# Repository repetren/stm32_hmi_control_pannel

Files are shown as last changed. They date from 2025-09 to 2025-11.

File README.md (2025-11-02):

# STM32 CAN Dashboard Panel

Control unit for generating CAN signals based on an STM32. Inputs from magnetic encoders, buttons, and a potentiometer.

My personal project with goal to expand my knowledge about industry standards communication protocols.

Created to provide interactive demo CAN inputs for my [Motorcycle Instrument Cluster project](https://github.com/repetren/moto_instrument_cluster).



Watch the video (https://youtu.be/6McVTvd34ow)

### [Watch demo and work in progress video on YouTube](https://youtu.be/6McVTvd34ow)



### Features:
- Timers for CAN frame transmission schedule  
- Buttons via EXTI
- Software button debounce
- LED indicators for power and mode indicators
- Two potentiometer modes for two CAN frames
- ADC with DMA for potentiometer sampling

### Power and ESD
- 5 V input, 3.3 V logic. Conversion through LD1117A regulator
- TVS diode for CAN bus and power input protection

## Project Structure

I'm using **[app.c](App/Src/app.c)** to avoid deal with USER CODE BLOCKs inside STM32 generated code.

**CAN_Control_Panel**

App:
- Inc - Header
- Src - Source - **main [app.c](App/Src/app.c)**

Core: Startup + HAL init (generated)
- Inc
- Src - **main.c** contains **app.c**

Docs:
- CAN message map

Hardware:
- PCB - Gerbers, BOM, circuit diagram
- 3DPrints - Knobs, buttons, frame .stl files

## Hardware
- STM32F446RET6 as main MCU
- 6 push buttons via EXTI interrupts
- 2 rotary encoders (AS5048B) over I2C
- 1 potentiometer with analog input
- CAN transceiver: SN65HVD230DR
- UART for debugging and serial output
- SWD interface for firmware flashing and debugging

## Software Architecture



The panel collects input data from physical controls and sensors, processes them periodically in the main loop, and sends formatted messages over CAN and UART.

| Input | Interface | Processed in | Purpose |
| :---: | --- | --- | --- |
| Buttons (6 pcs) | EXTI interrupts | EXTI + Debounce. | Gear, turn signals, potentiometer modes |
| Magnetic encoders (2 pcs) | I2C | `[encoder_remap](App/Src/encoder_utils.c)` | Angle to telemetry parameter |
| Potentiometer | ADC + DMA | `[fuel_and_temp_utils.c](App/Src/fuel_and_temp_utils.c)` | Fuel/temperature input (depending on mode) |

#### Periodic task handling ([app.c](App/Src/app.c))
Tasks are executed based on timing from the TIM14 timer.

|  Frequency | Task responsibilities |
| :---: | --- |
| **100 Hz** | Update telemetry, monitor temperature, send telemetry |
|  **50 Hz** | Update lights and send over CAN light frame |
|  **25 Hz** | Fuel conversion, range estimation, vehicle info broadcast, low fuel notification, CAN fuel frame send |

#### Output communication

| Output  | Used for |
| --- | --- |
| UART | Debug messages |
| CAN bus | Telemetry, light control, fuel, and notification frames sent to Raspberry Pi with CAN HAT |

## CAN Frame Map


## Build and run

### Requirements
 - VS Code
 - Installed [STM32CubeIDE for Visual Studio Code](https://marketplace.visualstudio.com/items?itemName=stmicroelectronics.stm32-vscode-extension)
 - [STLINK-V3MINIE](https://www.digikey.de/de/products/detail/stmicroelectronics/STLINK-V3MINIE/16284301)

### VS Code
1. Open repository folder
2. Configure project. CMD (CTRL) + Shift + P
```
Setup STM32Cube project(s)
```


3. Select device



4. Click "Save and close"

5. Run and debug



6. Select ST-LINK server

7. Select project .elf



8. Click "Continue" (F5)



## Future improvements
- Replacing big SWD 14-pin connector to 6-pin version

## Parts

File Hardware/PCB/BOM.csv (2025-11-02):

Reference | Qty | Value | DNP | Exclude from BOM | Exclude from Board | Footprint | Datasheet
C1,C2,C3,C4,C13 | 5 | 100nF |  |  |  | CL05B104KP5NNNC:CAPC1005X55N | ~
C5 | 1 | 2.2 µF |  |  |  | Capacitor_SMD:C_0402_1005Metric | ~
C6,C10 | 2 | 100 nF |  |  |  | CL05B104KP5NNNC:CAPC1005X55N | ~
C7,C15 | 2 | 4.7 µF |  |  |  | CL10A475KP8NNNC:CAPC1608X90N | ~
C8,C9 | 2 | 10μF |  |  |  | CL10A106KQ8NNNC:CAPC1608X90N | ~
C11,C12 | 2 | 20pF |  |  |  | C0603C200G8HACTU:CAPC17595_87N_KEM | ~
C14 | 1 | 10 uF |  |  |  | CL10A106KQ8NNNC:CAPC1608X90N | ~
CR1 | 1 | LD1117AS33TR |  |  |  | LD1117AS33TR:SOT-223_STM | https://www.st.com/resource/en/datasheet/ld1117a.pdf
D1,D2,D3,D4,D5,D9 | 6 | LED |  |  |  | LED_SMD:LED_1206_3216Metric | ~
D6 | 1 | SM712_SOT23 |  |  |  | Package_TO_SOT_SMD:SOT-23 | https://www.littelfuse.com/~/media/electronics/datasheets/tvs_diode_arrays/littelfuse_tvs_diode_array_sm712_datasheet.pdf.pdf
D7,D8 | 2 | SMF5V0A |  |  |  | Diode_SMD:D_SMF | https://www.vishay.com/doc?85881
DOWN_1,DOWN_2,LEFT_2,POT_MODE_1,RESET_1,RIGHT_2,UP_2 | 7 | B3FS-1012P |  |  |  | B3FS_1012P:B3FS-101_OMR | B3FS-1012P
J1,J2 | 2 | KF301-2P |  |  |  | KF301-2P:HANDSON_KF301-2P
J3 | 1 | FTSH-107-01-L-DV-K |  |  |  | FTSH_107_01_L_DV_K:SAMTEC_FTSH-107-01-L-DV-K
L1 | 1 | WE-CBF_0402 |  |  |  | 74279271:WE-CBF_0402_W1.5
Q1,Q2 | 2 | AS5048B-HTSP-500 |  |  |  | AS5048B-HTSP-500:TRANS_HTSP-500_AMS-M | AS5048B-HTSP-500
R1,R5,R7,R8,R9,R10,R11 | 7 | 120 Ohm |  |  |  | Resistor_SMD:R_0603_1608Metric | ~
R2,R3 | 2 | 4.7 kOhm |  |  |  | Resistor_SMD:R_0603_1608Metric | ~
R4 | 1 | 1 kOhm |  |  |  | Resistor_SMD:R_0603_1608Metric | ~
R6 | 1 | 10 kOhn |  |  |  | Resistor_SMD:R_0603_1608Metric | ~
R12 | 1 | 10 kOhm |  |  |  | Resistor_SMD:R_0603_1608Metric | ~
U1 | 1 | STM32F446RET6 |  |  |  | STM32F446RET6:QFP50P1200X1200X160-64N
U2 | 1 | P0915N-FC15BR10K |  |  |  | P0915N_FC15BR10K:SWITCH_C15BR10K_BIT | P0915N-FC15BR10K
U3 | 1 | SN65HVD230DR |  |  |  | SN65HVD230DR:SOIC127P599X175-8N
USART2 | 1 | ~ |  |  |  | Connector_PinHeader_2.54mm:PinHeader_1x04_P2.54mm_Vertical
Y1 | 1 | ECS-80-18-5PX-TR |  |  |  | ECS_80_18_5PX_TR:XTAL_ECS-80-18-5PX-TR

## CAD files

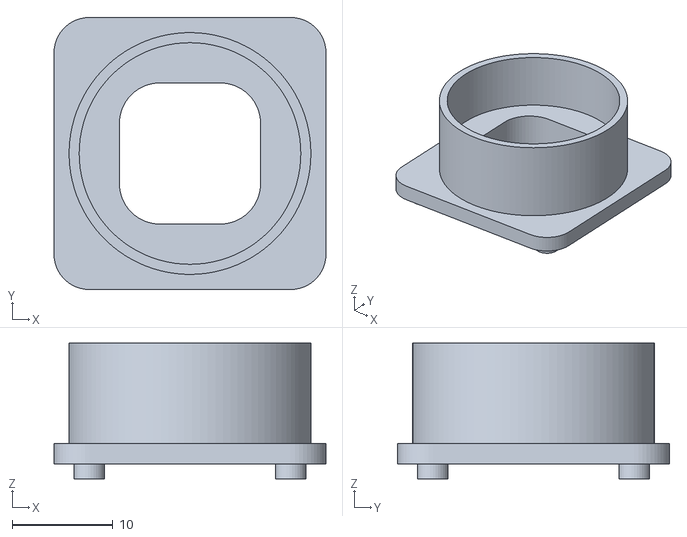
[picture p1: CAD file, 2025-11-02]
Hardware/3Dprints/Moto_HMI_ballbearing_holder_v002.stl
27.0 x 27.0 x 13.5

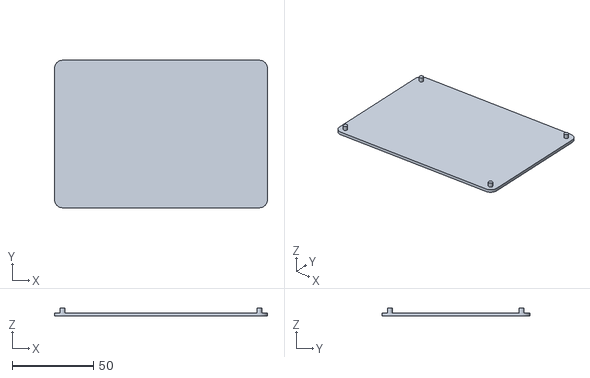
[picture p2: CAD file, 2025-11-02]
Hardware/3Dprints/Moto_HMI_bottom_blate_v002.stl
131.0 x 90.8 x 5.00

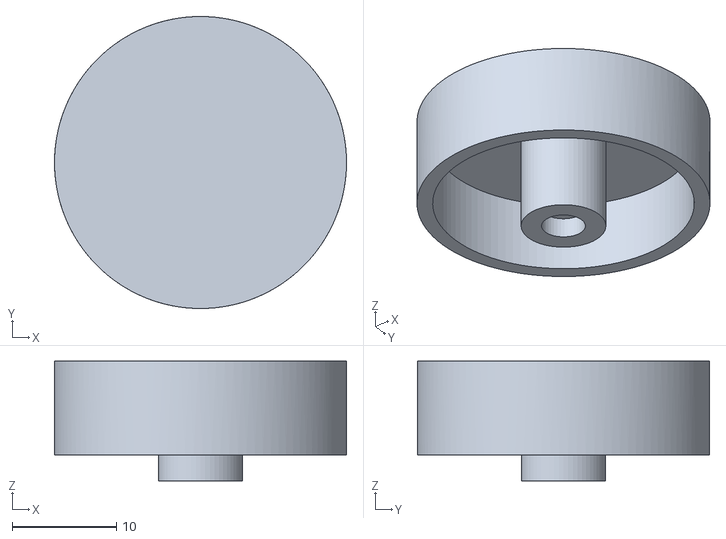
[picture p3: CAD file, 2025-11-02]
Hardware/3Dprints/Moto_HMI_Knob_v004.stl
28.0 x 28.0 x 11.5

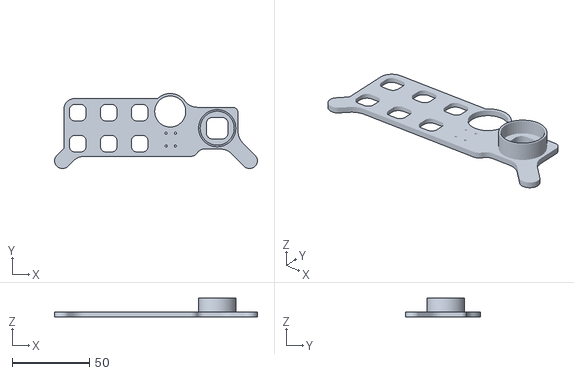
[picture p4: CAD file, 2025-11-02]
Hardware/3Dprints/Control_pannel_frame_v003.stl
131.0 x 48.4 x 12.0

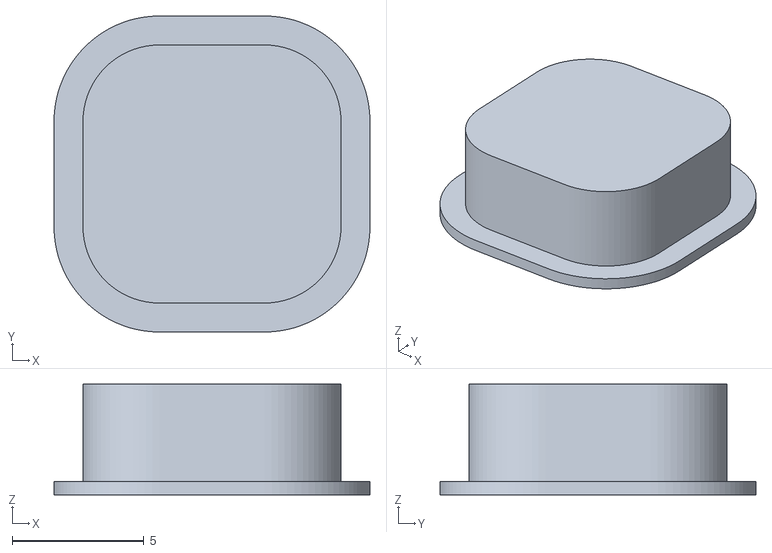
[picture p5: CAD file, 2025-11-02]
Hardware/3Dprints/control_pannel_button_v005.stl
12.0 x 12.0 x 4.20

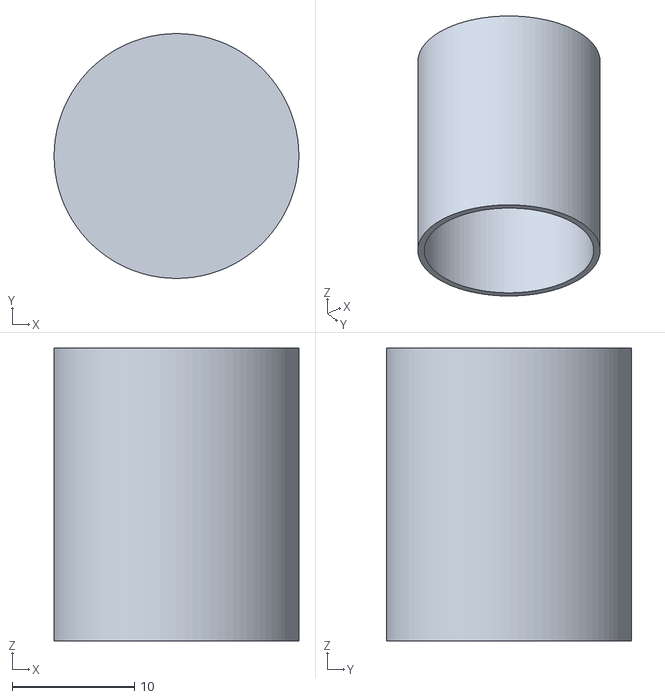
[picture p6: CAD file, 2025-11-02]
Hardware/3Dprints/Control_Pannel_knob_v001.stl
20.1 x 20.1 x 24.0

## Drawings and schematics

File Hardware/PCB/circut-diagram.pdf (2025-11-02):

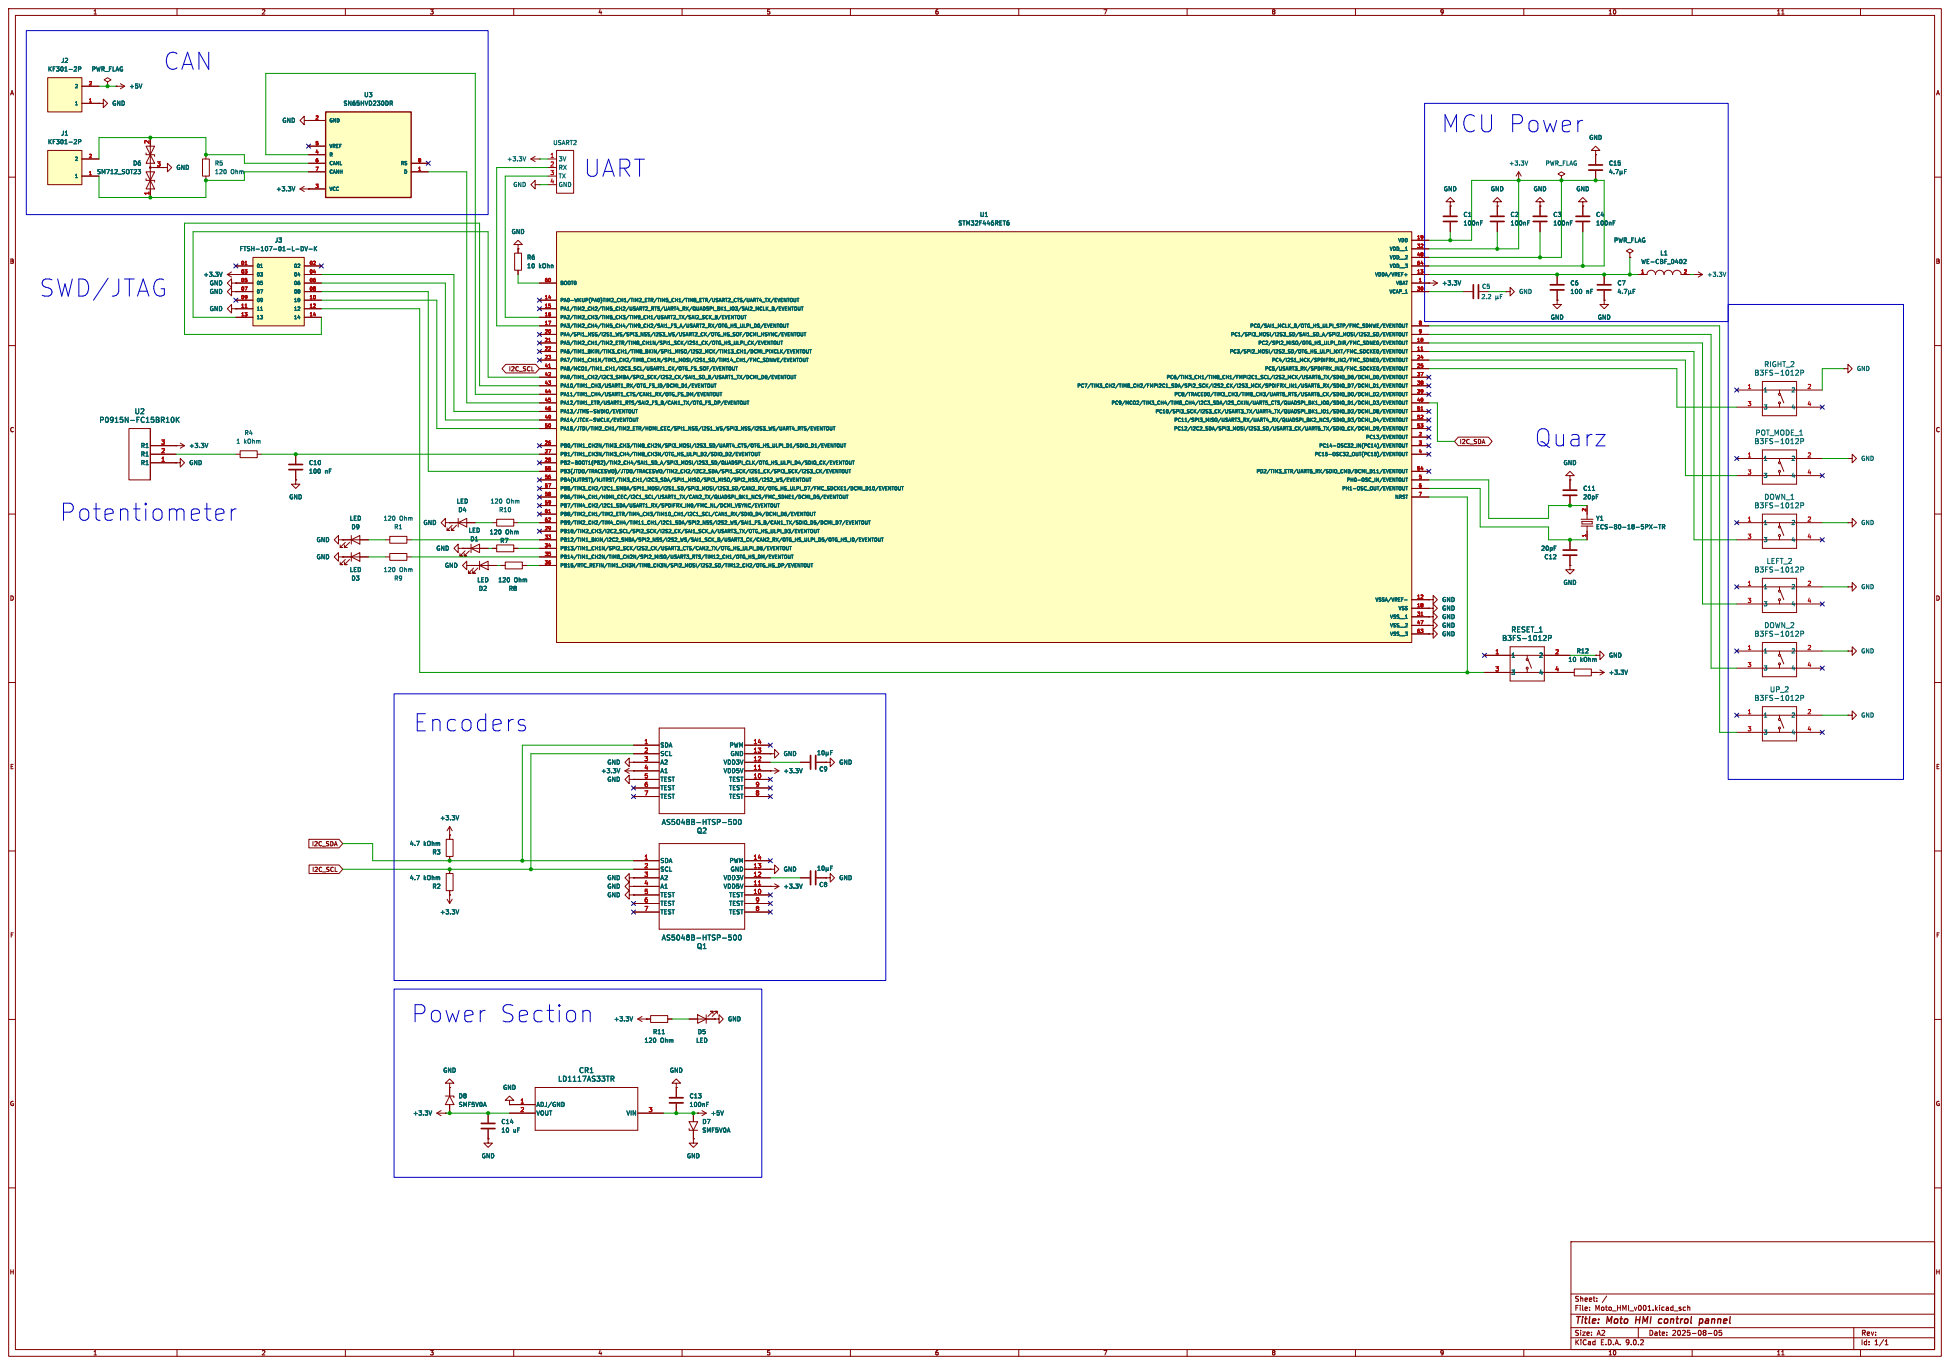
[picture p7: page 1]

GNDGND GND GND GND GND GND

GND GND GND GND GND

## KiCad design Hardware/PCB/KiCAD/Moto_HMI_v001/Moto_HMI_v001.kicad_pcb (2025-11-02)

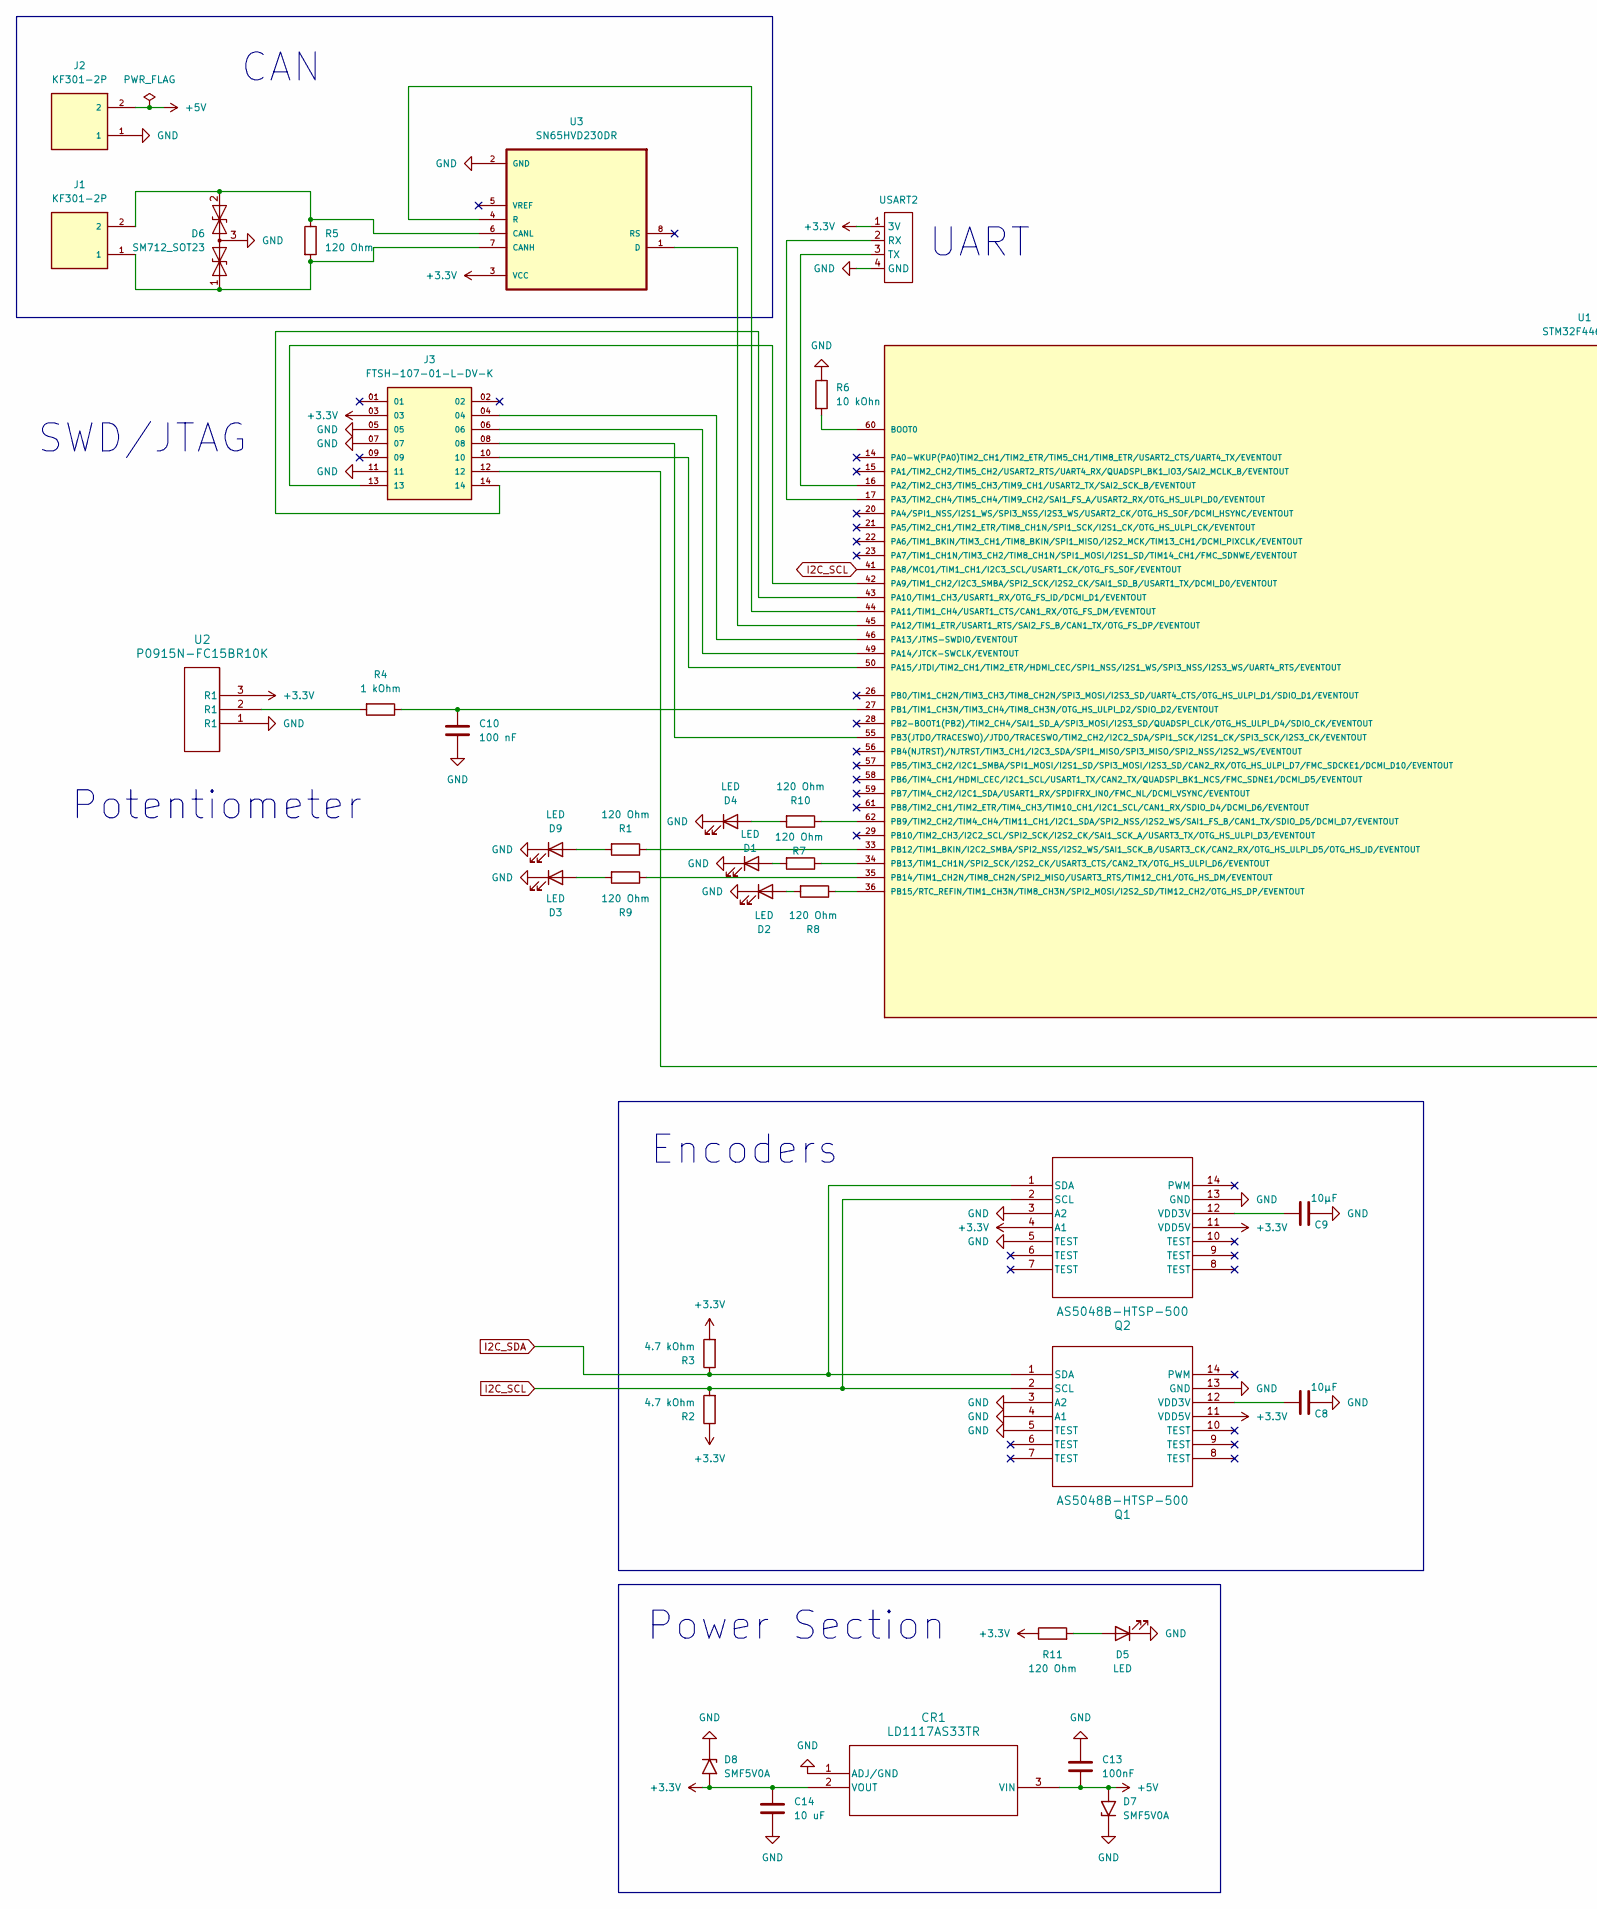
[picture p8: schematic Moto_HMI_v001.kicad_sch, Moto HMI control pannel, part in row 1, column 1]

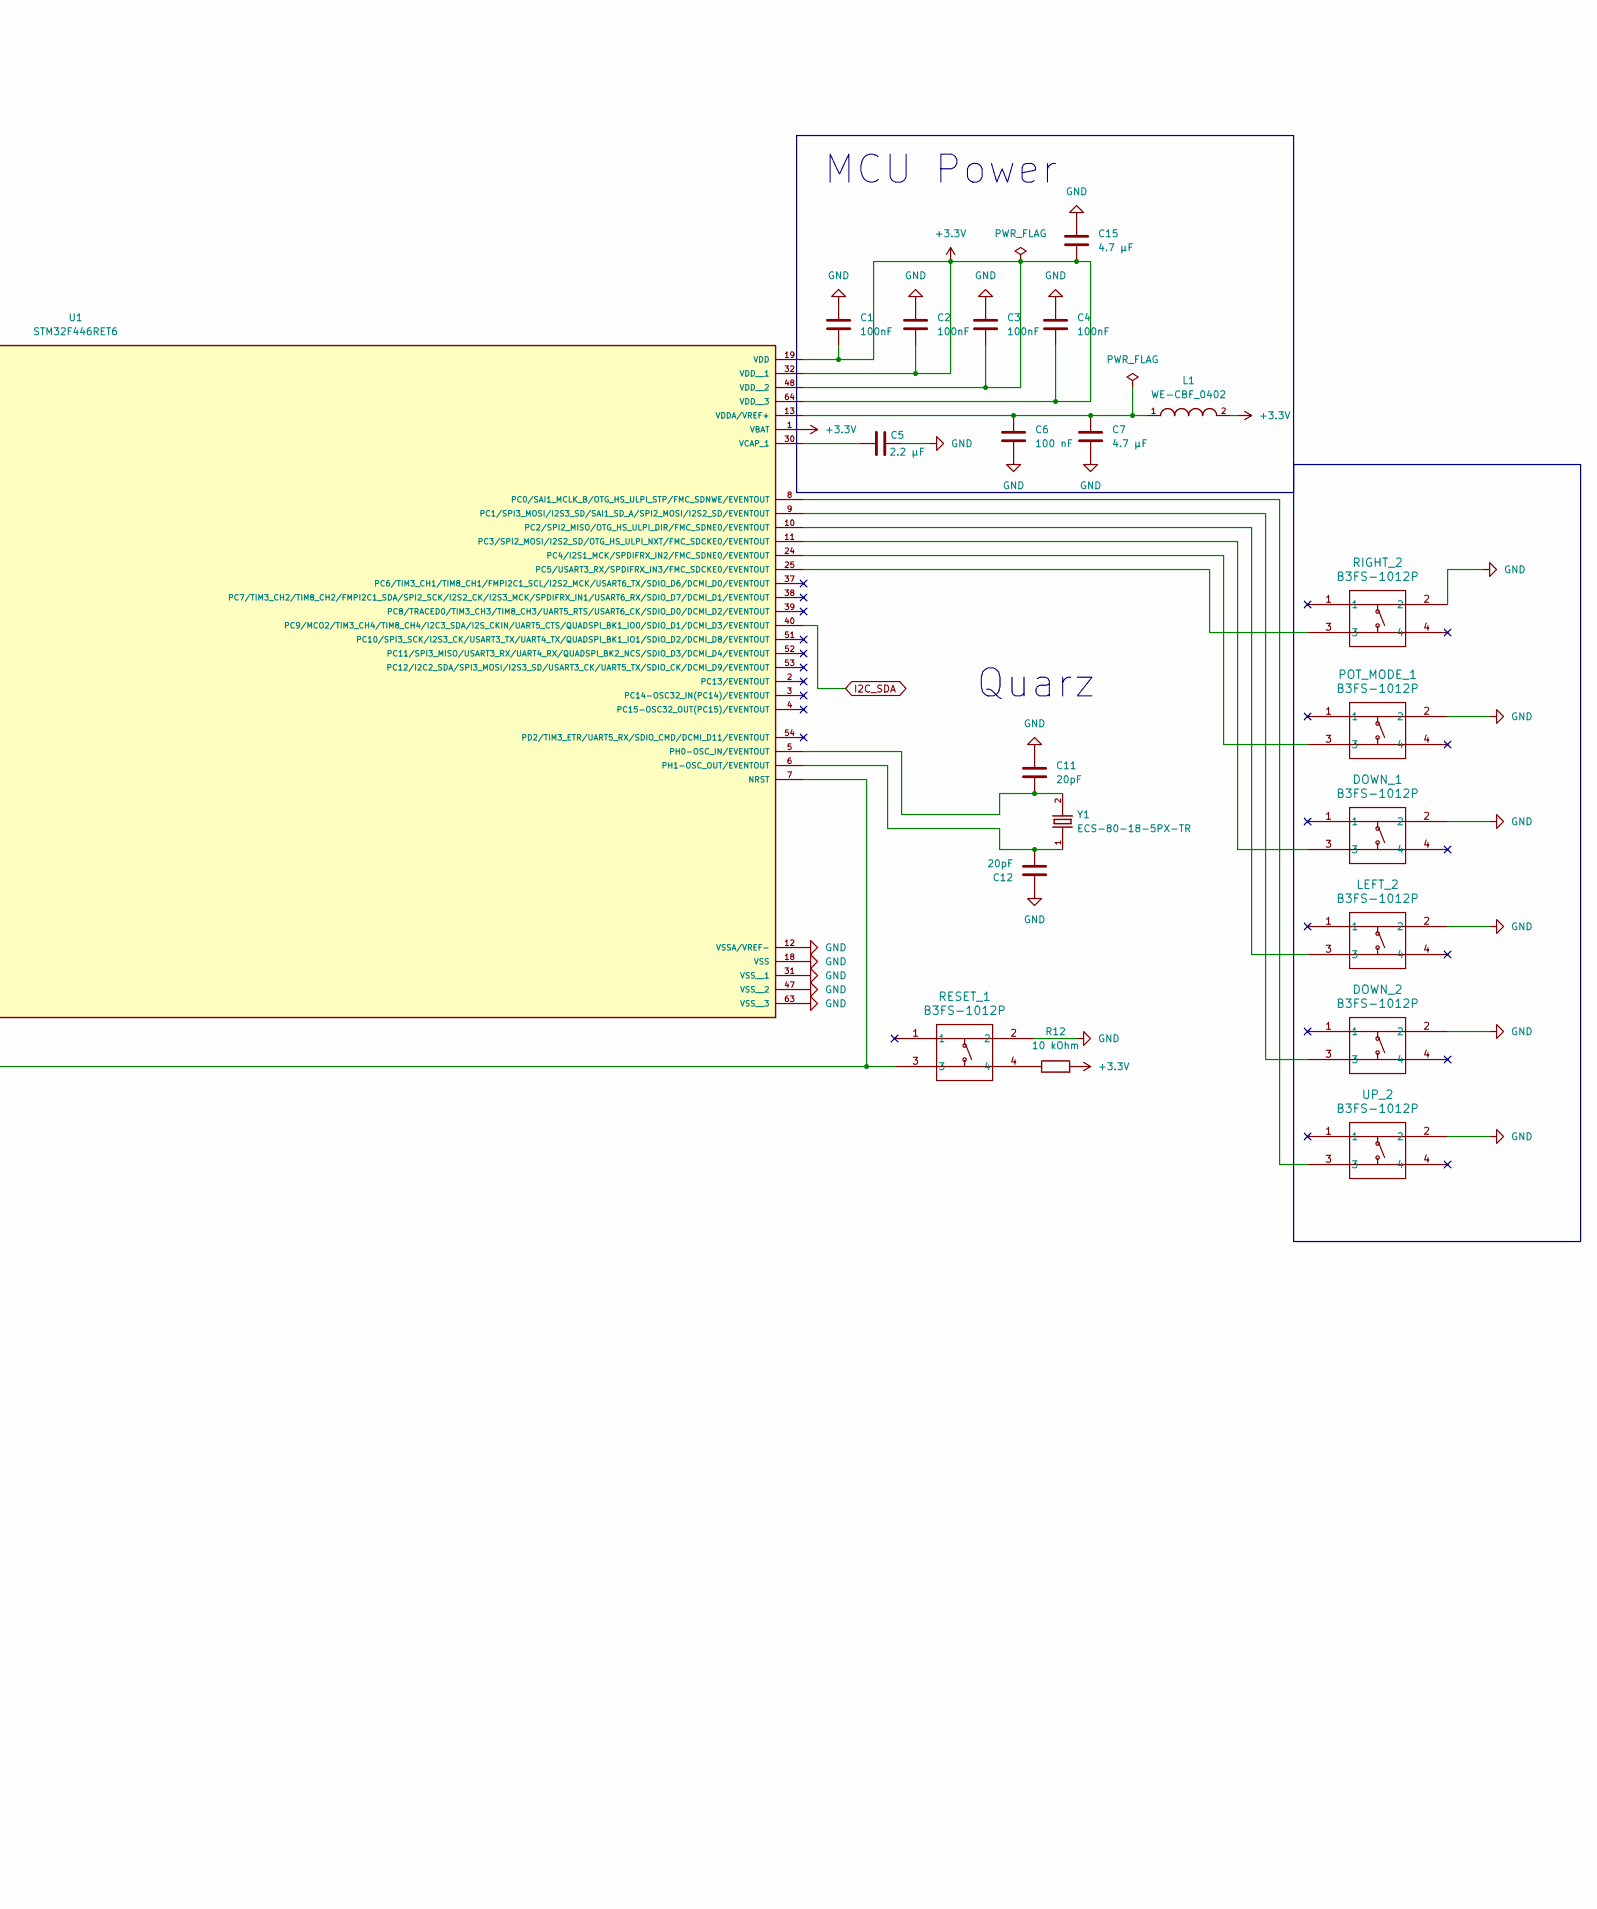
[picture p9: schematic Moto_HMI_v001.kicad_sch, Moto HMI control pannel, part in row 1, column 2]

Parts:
C1, C2, C3, C4, C13: 100nF; CAPC1005X55N
C5: 2.2 µF; C_0402_1005Metric
C6, C10: 100 nF; CAPC1005X55N
C7, C15: 4.7 µF; CAPC1608X90N
C8, C9: 10μF; CAPC1608X90N
C11, C12: 20pF; CAPC17595_87N_KEM
C14: 10 uF; CAPC1608X90N
CR1: LD1117AS33TR; SOT-223_STM
D1, D2, D3, D4, D5, D9: LED; LED_1206_3216Metric
D6: SM712_SOT23; SOT-23
D7, D8: SMF5V0A; D_SMF
DOWN_1, DOWN_2: B3FS-1012P; B3FS-101_OMR
J1, J2: KF301-2P; HANDSON_KF301-2P; PARTREV NA
J3: FTSH-107-01-L-DV-K; SAMTEC_FTSH-107-01-L-DV-K; PARTREV R
L1: WE-CBF_0402; WE-CBF_0402_W1.5
LEFT_2: B3FS-1012P; B3FS-101_OMR
POT_MODE_1: B3FS-1012P; B3FS-101_OMR
Q1, Q2: AS5048B-HTSP-500; TRANS_HTSP-500_AMS-M
R1, R5, R7, R8, R9, R10, R11: 120 Ohm; R_0603_1608Metric
R2, R3: 4.7 kOhm; R_0603_1608Metric
R4: 1 kOhm; R_0603_1608Metric
R6: 10 kOhn; R_0603_1608Metric
R12: 10 kOhm; R_0603_1608Metric
RESET_1: B3FS-1012P; B3FS-101_OMR
RIGHT_2: B3FS-1012P; B3FS-101_OMR
U1: STM32F446RET6; QFP50P1200X1200X160-64N; PARTREV 6
U2: P0915N-FC15BR10K; SWITCH_C15BR10K_BIT
U3: SN65HVD230DR; SOIC127P599X175-8N
UP_2: B3FS-1012P; B3FS-101_OMR
USART2: PinHeader_1x04_P2.54mm_Vertical
Y1: ECS-80-18-5PX-TR; XTAL_ECS-80-18-5PX-TR; PARTREV 2017

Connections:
+3.3V: C1.2, C2.2, C3.2, C4.2, C14.1, C15.2, CR1.2 (VOUT), D8.2 (A2), J3.03, L1.2, Q1.11 (VDD5V), Q2.4 (A1), Q2.11 (VDD5V), R2.1, R3.2, R11.1, R12.2, U1.1 (VBAT), U1.19 (VDD), U1.32 (VDD__1), U1.48 (VDD__2), U1.64 (VDD__3), U2.3 (R1), U3.3 (VCC), USART2.1 (3V)
+5V: C13.2, CR1.3 (VIN), D7.2 (A2), J2.2
GND: C1.1, C2.1, C3.1, C4.1, C5.1, C6.2, C7.2, C8.2, C9.2, C10.2, C11.1, C12.1, C13.1, C14.2, C15.1, CR1.1 (ADJ/GND), D1.1 (K), D2.1 (K), D3.1 (K), D4.1 (K), D5.1 (K), D6.3 (common), D7.1 (A1), D8.1 (A1), D9.1 (K), DOWN_1.2, DOWN_2.2, J2.1, J3.05, J3.07, J3.11, LEFT_2.2, POT_MODE_1.2, Q1.3 (A2), Q1.4 (A1), Q1.5 (TEST), Q1.13 (GND), Q2.3 (A2), Q2.5 (TEST), Q2.13 (GND), R6.1, RESET_1.2, RIGHT_2.2, U1.12 (VSSA/VREF-), U1.18 (VSS), U1.31 (VSS__1), U1.47 (VSS__2), U1.63 (VSS__3), U2.1 (R1), U3.2 (GND), UP_2.2, USART2.4 (GND); also elsewhere on the board
I2C_SCL: Q1.2 (SCL), Q2.2 (SCL), R2.2, U1.41 (PA8/MCO1/TIM1_CH1/I2C3_SCL/USART1_CK/OT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)
I2C_SDA: Q1.1 (SDA), Q2.1 (SDA), R3.1, U1.40 (PC9/MCO2/TIM3_CH4/TIM8_CH4/I2C3_SDA/I2S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)
unnamed: D1.2 (A), R7.2
unnamed: D2.2 (A), R8.2
unnamed: D3.2 (A), R9.2
unnamed: D4.2 (A), R10.2
unnamed: D5.2 (A), R11.2
unnamed: D6.1 (A1), J1.1, R5.2, U3.7 (CANH)
unnamed: D6.2 (A2), J1.2, R5.1, U3.6 (CANL)
unnamed: D9.2 (A), R1.2
unnamed: C8.1, Q1.12 (VDD3V)
unnamed: C9.1, Q2.12 (VDD3V)
unnamed: R4.2, U2.2 (R1)
unnamed: R12.1, RESET_1.4
unnamed: R6.2, U1.60 (BOOT0)
unnamed: J3.12, RESET_1.3, U1.7 (NRST)
unnamed: U1.16 (PA2/TIM2_CH3/TIM5_CH3/TIM9_CH1/USART2_T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), USART2.3 (TX)
unnamed: U1.17 (PA3/TIM2_CH4/TIM5_CH4/TIM9_CH2/SAI1_FS_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), USART2.2 (RX)
unnamed: J3.13, U1.42 (PA9/TIM1_CH2/I2C3_SMBA/SPI2_SCK/I2S2_CK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)
unnamed: J3.14, U1.43 (PA10/TIM1_CH3/USART1_RX/OTG_FS_ID/DCMI_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)
unnamed: U1.44 (PA11/TIM1_CH4/USART1_CTS/CAN1_RX/OTG_FS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), U3.4 (R)
unnamed: U1.45 (PA12/TIM1_ETR/USART1_RTS/SAI2_FS_B/CAN1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), U3.1 (D)
unnamed: J3.04, U1.46 (PA13/JTMS-SWDIO/EVENTOUT)
unnamed: J3.06, U1.49 (PA14/JTCK-SWCLK/EVENTOUT)
unnamed: J3.10, U1.50 (PA15/JTDI/TIM2_CH1/TIM2_ETR/HDMI_CEC/SP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)
unnamed: C10.1, R4.1, U1.27 (PB1/TIM1_CH3N/TIM3_CH4/TIM8_CH3N/OTG_HS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)
unnamed: J3.08, U1.55 (PB3(JTDO/TRACESWO)/JTDO/TRACESWO/TIM2_C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)
unnamed: R10.1, U1.62 (PB9/TIM2_CH2/TIM4_CH4/TIM11_CH1/I2C1_SD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)
unnamed: R1.1, U1.33 (PB12/TIM1_BKIN/I2C2_SMBA/SPI2_NSS/I2S2_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)
unnamed: R7.1, U1.34 (PB13/TIM1_CH1N/SPI2_SCK/I2S2_CK/USART3_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)
unnamed: R9.1, U1.35 (PB14/TIM1_CH2N/TIM8_CH2N/SPI2_MISO/USAR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)
unnamed: R8.1, U1.36 (PB15/RTC_REFIN/TIM1_CH3N/TIM8_CH3N/SPI2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)
unnamed: U1.8 (PC0/SAI1_MCLK_B/OTG_HS_ULPI_STP/FMC_SDN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), UP_2.3
unnamed: DOWN_2.3, U1.9 (PC1/SPI3_MOSI/I2S3_SD/SAI1_SD_A/SPI2_MO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)
unnamed: LEFT_2.3, U1.10 (PC2/SPI2_MISO/OTG_HS_ULPI_DIR/FMC_SDNE0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)
unnamed 38: DOWN_1.3, U1.11 (PC3/SPI2_MOSI/I2S2_SD/OTG_HS_ULPI_NXT/F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); also elsewhere on the board
unnamed: POT_MODE_1.3, U1.24 (PC4/I2S1_MCK/SPDIFRX_IN2/FMC_SDNE0/EVEN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)
unnamed: RIGHT_2.3, U1.25 (PC5/USART3_RX/SPDIFRX_IN3/FMC_SDCKE0/EV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)
unnamed: C11.2, U1.5 (PH0-OSC_IN/EVENTOUT), Y1.2
unnamed: C12.2, U1.6 (PH1-OSC_OUT/EVENTOUT), Y1.1
unnamed: C5.2, U1.30 (VCAP_1)
unnamed: C6.1, C7.1, L1.1, U1.13 (VDDA/VREF+)

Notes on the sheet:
Encoders
Quarz
SWD/JTAG
Power Section
UART
MCU Power
CAN
Potentiometer

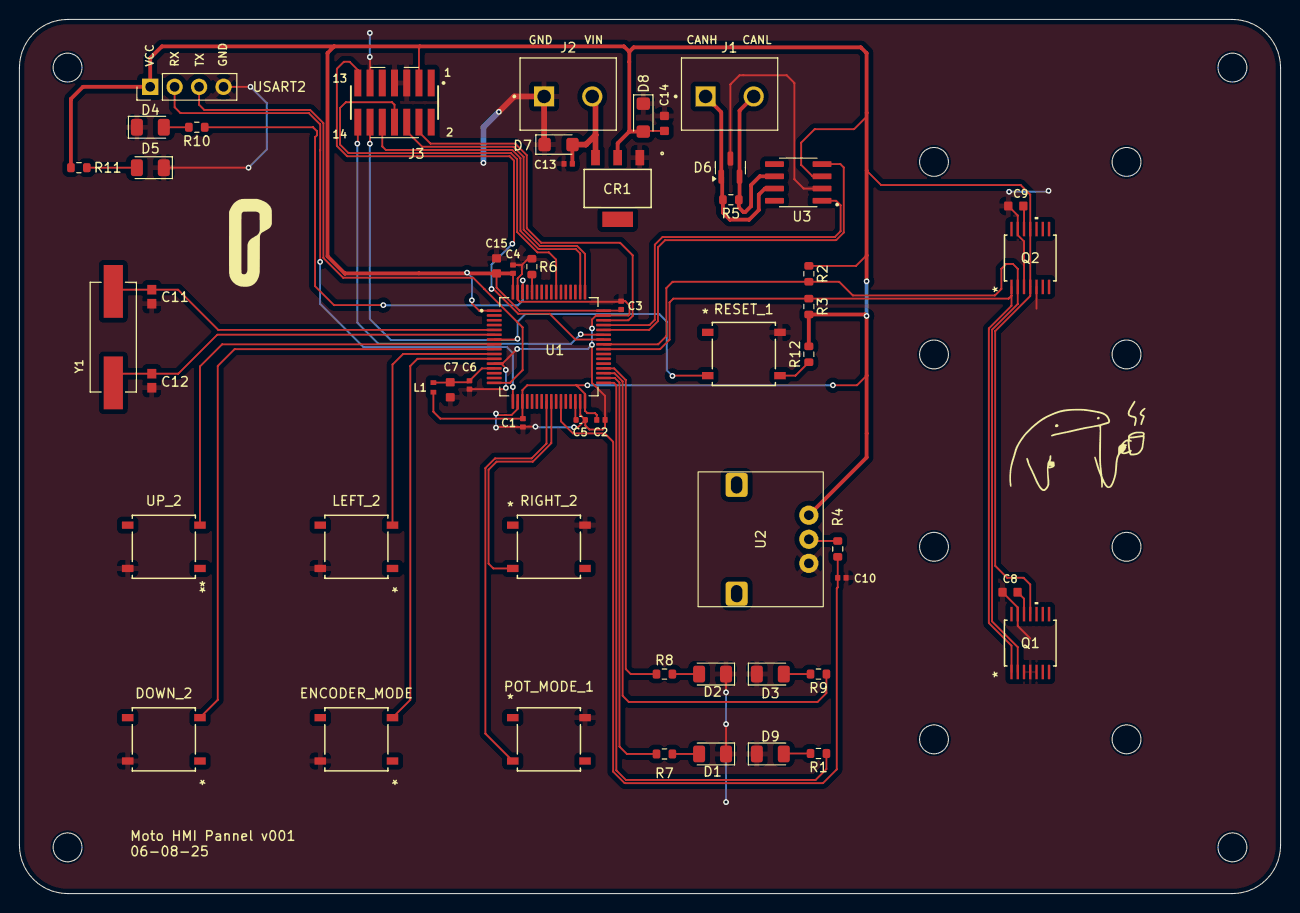
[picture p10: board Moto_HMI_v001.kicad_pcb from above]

Board: 4 copper layers, 131.0 x 90.8 mm, 55 parts (0 on the bottom side), 45 nets.

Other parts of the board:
ENCODER_MODE  : B3FS-1012P; B3FS-101_OMR

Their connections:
GND: ENCODER_MODE.2; also elsewhere on the board
unnamed 38: ENCODER_MODE.3; also elsewhere on the board

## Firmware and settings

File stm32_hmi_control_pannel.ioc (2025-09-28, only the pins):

Mcu.UserName=STM32F446RETx
PA11.Signal=CAN1_RX
PA12.Signal=CAN1_TX
PA13.Signal=SYS_JTMS-SWDIO
PA14.Signal=SYS_JTCK-SWCLK
PA2.Signal=USART2_TX
PA3.Signal=USART2_RX
PA8.Signal=I2C3_SCL
PB1.Signal=ADCx_IN9
PB14.GPIO_Label=LED_2
PB14.Signal=GPIO_Output
PB15.GPIO_Label=LED_1
PB15.Signal=GPIO_Output
PC0.GPIO_Label=BTN_UP
PC0.Signal=GPXTI0
PC1.GPIO_Label=BTN_DOWN
PC1.Signal=GPXTI1
PC2.GPIO_Label=BTN_LEFT
PC2.Signal=GPXTI2
PC3.GPIO_Label=LIGHT_MODE
PC3.Signal=GPXTI3
PC4.GPIO_Label=BTN_POT_MODE
PC4.Signal=GPXTI4
PC5.GPIO_Label=BTN_RIGHT
PC5.Signal=GPXTI5
PC9.Signal=I2C3_SDA
PH0-OSC_IN.Signal=RCC_OSC_IN
PH1-OSC_OUT.Signal=RCC_OSC_OUT

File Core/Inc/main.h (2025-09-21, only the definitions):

#define BTN_UP_Pin GPIO_PIN_0
#define BTN_UP_GPIO_Port GPIOC
#define BTN_UP_EXTI_IRQn EXTI0_IRQn
#define BTN_DOWN_Pin GPIO_PIN_1
#define BTN_DOWN_GPIO_Port GPIOC
#define BTN_DOWN_EXTI_IRQn EXTI1_IRQn
#define BTN_LEFT_Pin GPIO_PIN_2
#define BTN_LEFT_GPIO_Port GPIOC
#define BTN_LEFT_EXTI_IRQn EXTI2_IRQn
#define LIGHT_MODE_Pin GPIO_PIN_3
#define LIGHT_MODE_GPIO_Port GPIOC
#define LIGHT_MODE_EXTI_IRQn EXTI3_IRQn
#define BTN_POT_MODE_Pin GPIO_PIN_4
#define BTN_POT_MODE_GPIO_Port GPIOC
#define BTN_POT_MODE_EXTI_IRQn EXTI4_IRQn
#define BTN_RIGHT_Pin GPIO_PIN_5
#define BTN_RIGHT_GPIO_Port GPIOC
#define BTN_RIGHT_EXTI_IRQn EXTI9_5_IRQn
#define LED_2_Pin GPIO_PIN_14
#define LED_2_GPIO_Port GPIOB
#define LED_1_Pin GPIO_PIN_15
#define LED_1_GPIO_Port GPIOB

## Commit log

2025-09-21 Add all buttons, encoders, potentiometer, and LEDs
2025-09-24 Distribute CAN frames for dedicated frequences

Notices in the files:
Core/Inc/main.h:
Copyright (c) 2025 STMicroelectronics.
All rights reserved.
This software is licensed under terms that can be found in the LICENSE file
